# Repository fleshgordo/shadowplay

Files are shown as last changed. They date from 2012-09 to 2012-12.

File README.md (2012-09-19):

---------------------------------------------------------------

TIAN shadowplay - robotic light installation

Copyright Gordan Savicic 2012.

This program is free software: you can redistribute it
and/or modify it under the terms of the GNU Lesser General
Public License as published by the Free Software Foundation,
either version 3 of the License, or (at your option) any 
later version.

This program is distributed in the hope that it will be
useful, but WITHOUT ANY WARRANTY; without even the implied
warranty of MERCHANTABILITY or FITNESS FOR A PARTICULAR
PURPOSE.  See the GNU Lesser General Public License for more
details.

You should have received a copy of the GNU Lesser General
Public License along with this program.  If not, see
<http://www.gnu.org/licenses/>.

---------------------------------------------------------------

Shadowplay is a light installation for TIAN's chandelier
(www.tian-vienna.com) 
Concept & Production by design agency STRUKT Vienna 
(www.strukt.com) 
Light Design & Hardware by Gordan Savicic 
(www.yugo.at)

Two pan/tilt robotic units equipped with 10W LEDs were
installed inside the chandelier.  Through algorithmic
controlling of light positioning and brightness (PWM), they
produce different shadows along the ceiling and walls,
inviting the participator to experience various
patterns and reflections which subsequently form
their own spatial narrative.

---------------------------------------------------------------

Main hardware parts (see /schematics folder for CAD files):

* Arduino Mega (www.arduino.cc/en/Main/ArduinoBoardMega)
* Wifi Shield (www.arduino.cc/en/Main/ArduinoWiFiShield)
* 10W warm-white LEDs (www.reichelt.de) Constant Current
* Drivers BUCK (www.led-tech.de) 
* Glass Lenses (Lens Reflector 10W www.hero-ledstore.com)
* Custom PCB 
* Custom Aluminium pan/tilt unit (see /cnc folder for drawings)
  based on Lynx B Pan and Tilt kit (www.lynxmotion.com)

Software:

* written in C (see /firmware folder)

---------------------------------------------------------------

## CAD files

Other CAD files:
cnc/PANTILT_WITHOUTLENS.DXF
cnc/PANTILT_WITHLENS.DXF
cnc/PANTILT_MOUNTINGPLATE.DXF
cnc/PANTILT_MOUNTINGPLATE.DWG
cnc/PANTILT_WITHLENS.DWG
cnc/PANTILT_WITHOUTLENS.DWG

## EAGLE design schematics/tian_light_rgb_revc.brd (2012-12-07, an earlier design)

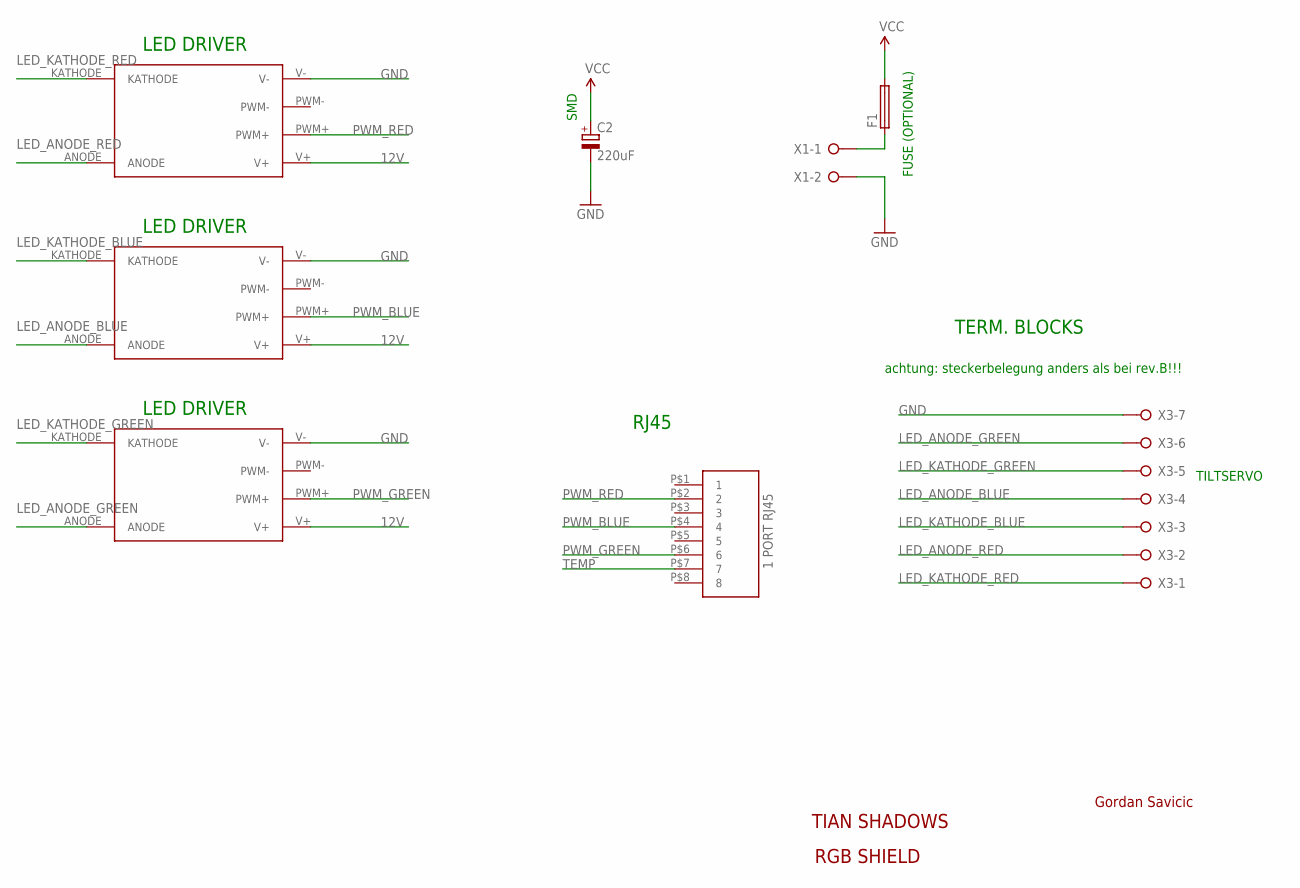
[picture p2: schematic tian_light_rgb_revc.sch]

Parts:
C2: 220uF; PANASONIC_F
F1: SH22,5
U$1, U$2, U$3: BUCK_LED_DRIVER
U$5: 1PORT_ETHERNET
X1: W237-02P; W237-132
X3: W237-07P; W237-7P

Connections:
12V: C2.+, F1.2, U$1.V+, U$2.V+, U$3.V+
GND: C2.-, U$1.V-, U$2.V-, U$3.V-, X1.2, X3.7
LED_ANODE_BLUE: U$2.ANODE, X3.4
LED_ANODE_GREEN: U$3.ANODE, X3.6
LED_ANODE_RED: U$1.ANODE, X3.2
LED_KATHODE_BLUE: U$2.KATHODE, X3.3
LED_KATHODE_GREEN: U$3.KATHODE, X3.5
LED_KATHODE_RED: U$1.KATHODE, X3.1
unnamed: F1.1, X1.1
PWM_BLUE: U$2.PWM+, U$5.P$4 (4)
PWM_GREEN: U$3.PWM+, U$5.P$6 (6)
PWM_RED: U$1.PWM+, U$5.P$2 (2)
TEMP: U$5.P$7 (7)

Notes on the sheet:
TILTSERVO
TIAN SHADOWS
RGB SHIELD
Gordan Savicic
RJ45
TERM. BLOCKS
LED DRIVER
achtung: steckerbelegung anders als bei rev.B!!!
FUSE (OPTIONAL)
SMD

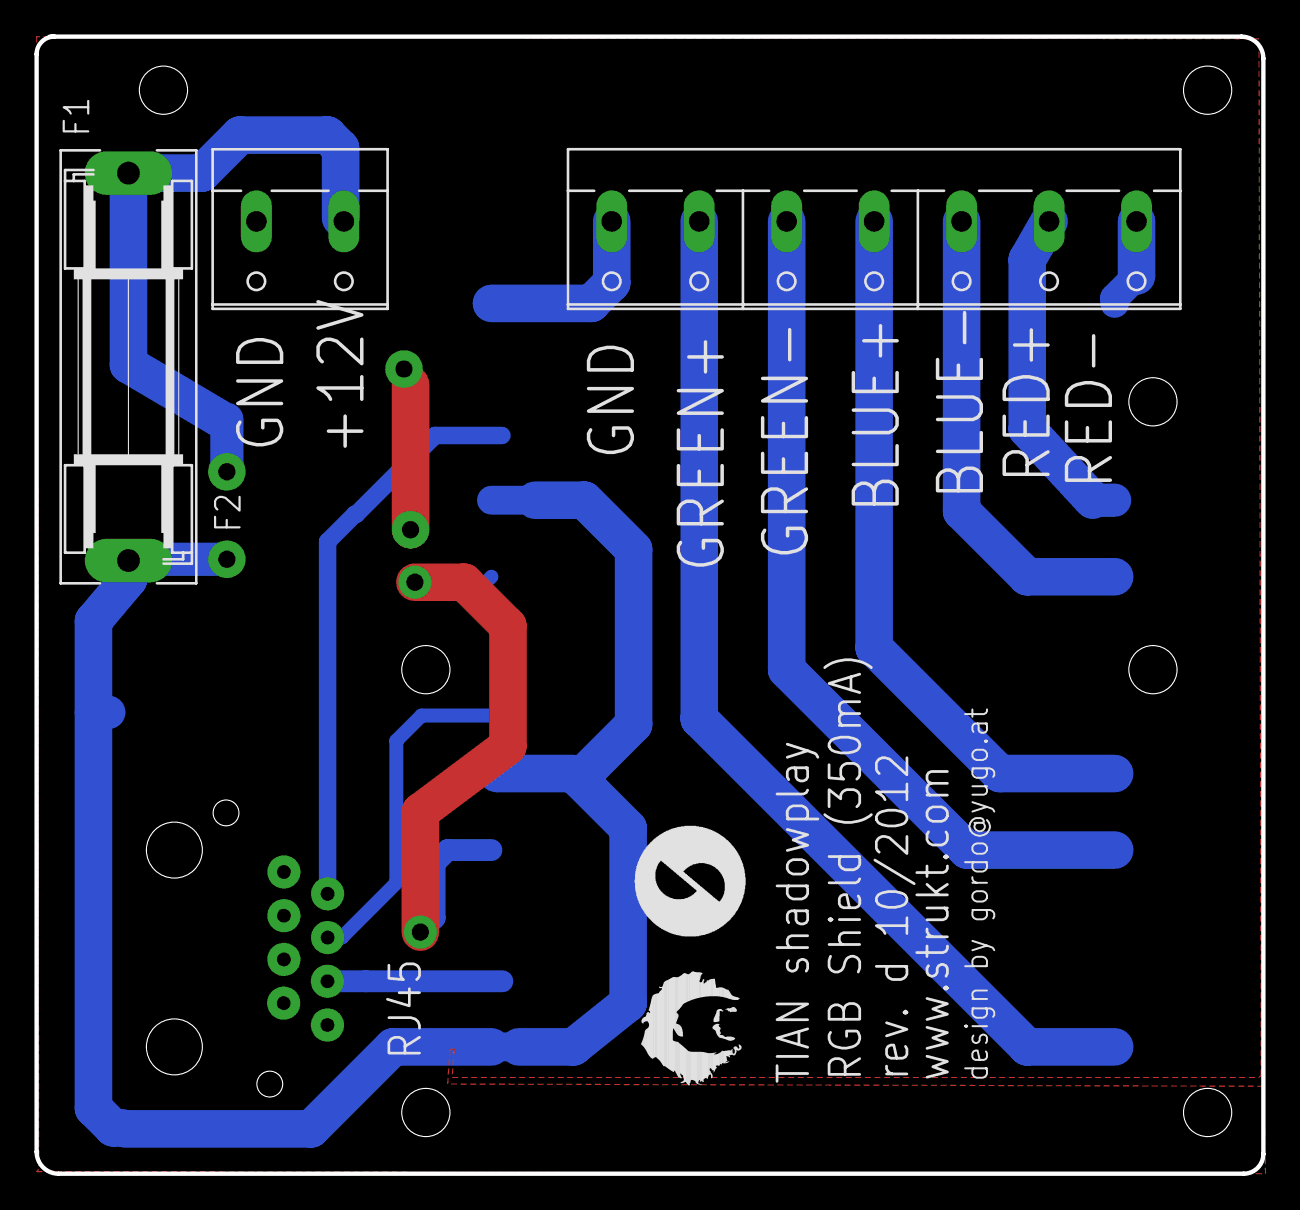
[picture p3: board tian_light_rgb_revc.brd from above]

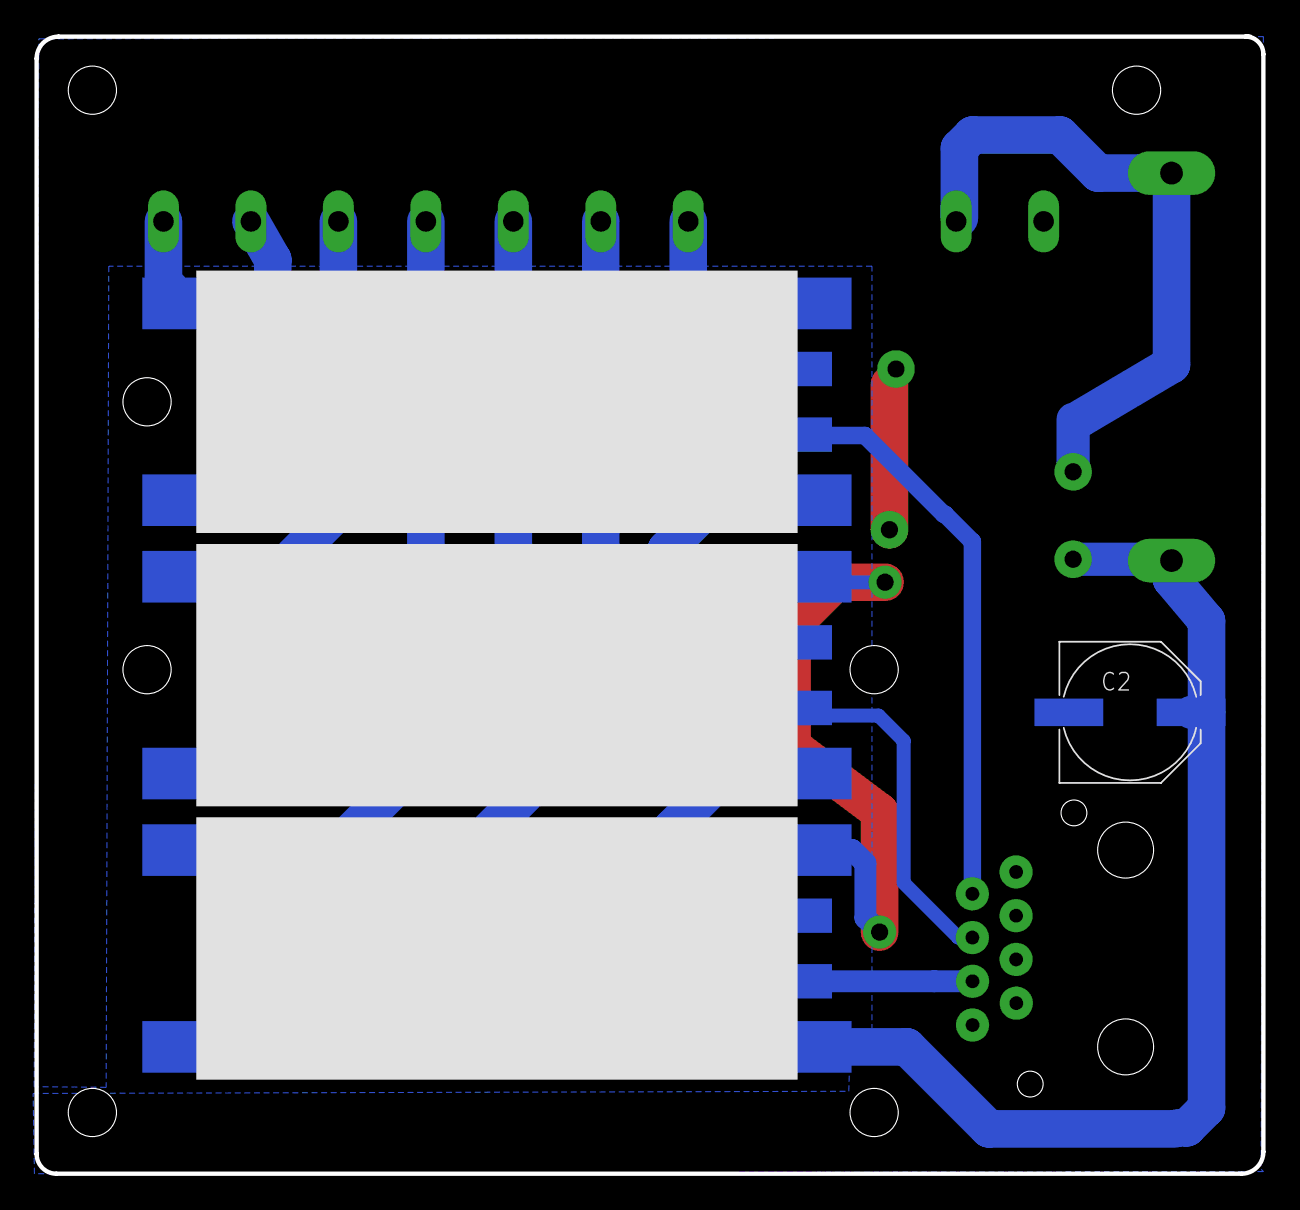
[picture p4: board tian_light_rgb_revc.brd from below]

Board: 2 copper layers, 71.2 x 66.0 mm, 8 parts (5 on the bottom side), 12 nets.

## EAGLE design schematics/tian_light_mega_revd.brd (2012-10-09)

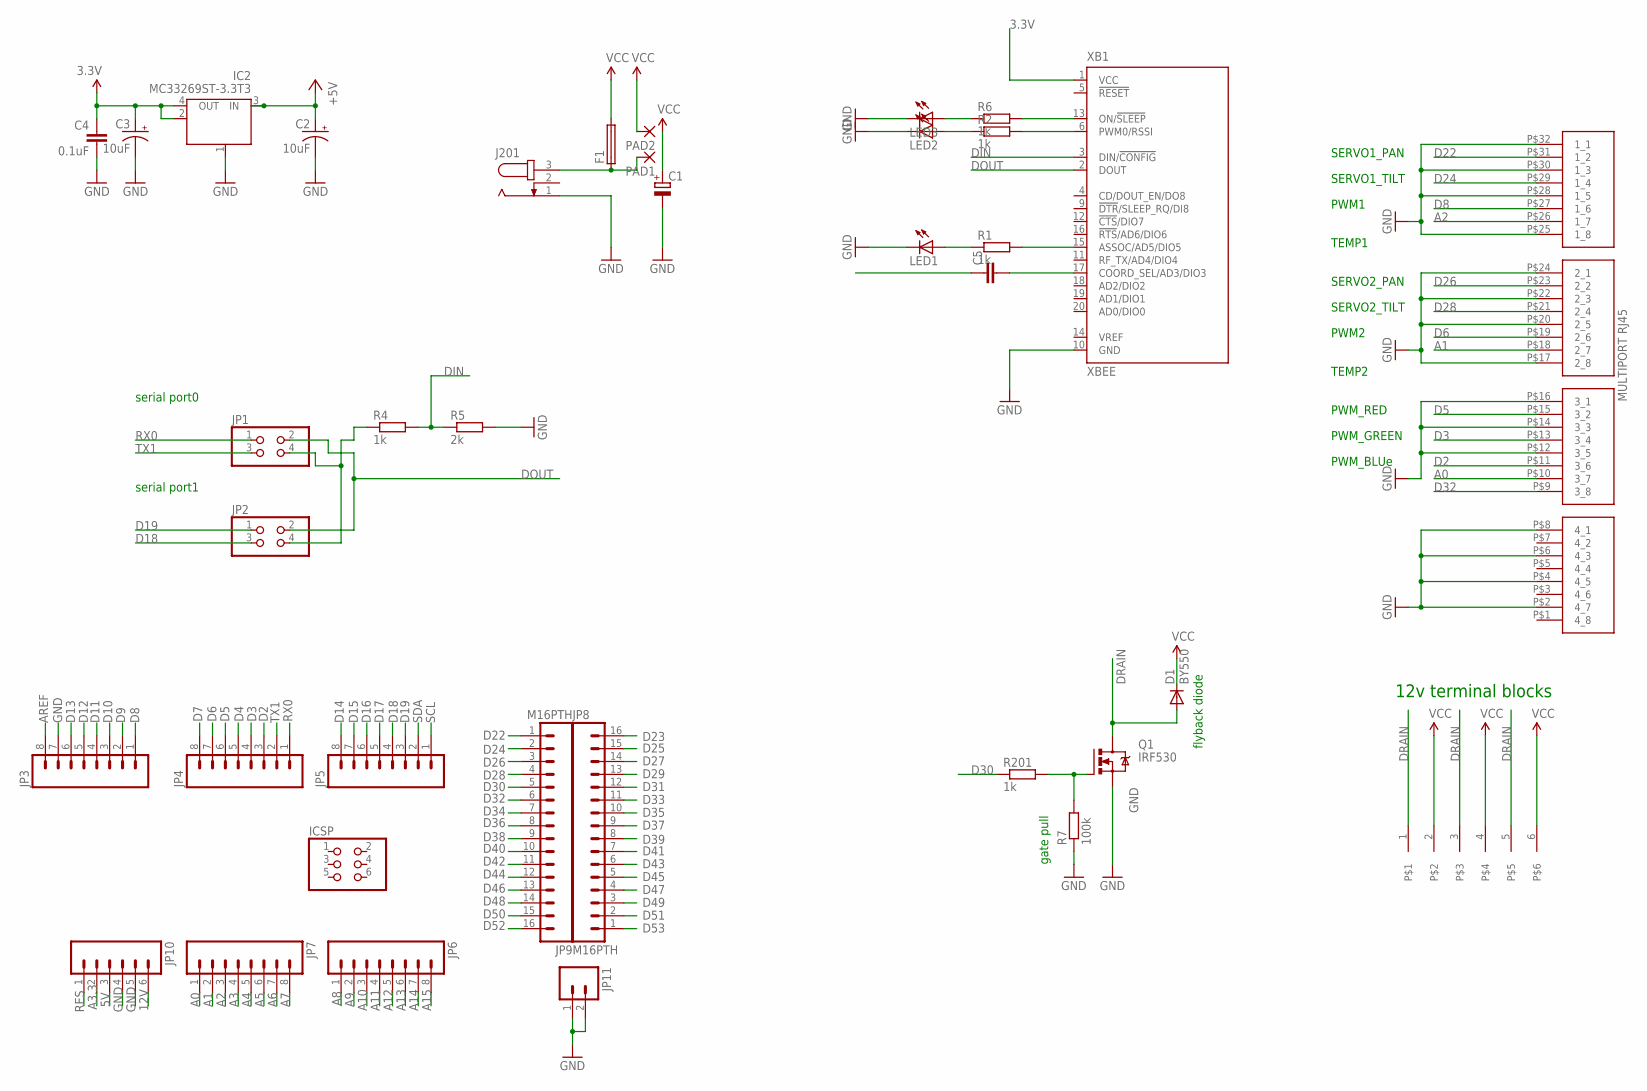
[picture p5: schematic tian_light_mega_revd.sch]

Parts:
C1: CPOL-EU153CLV-0605; 153CLV-0605
C2, C3: 10uF; EIA3216
C4: 0.1uF; 0603-CAP
C5: C-EUC0805; C0805
D1: BY550; DO27-15
F1: SH22,5
IC2: MC33269ST-3.3T3; SOT223
ICSP: PINHD-2X3; 2X03
J201: JACK-PLUG0; SPC4077
JP1, JP2: PINHD-2X2; 2X02
JP3, JP4, JP5, JP6, JP7: M08LONGPADS; 1X08_LONGPADS
JP8, JP9: M16PTH; 1X16
JP10: M06SIP; 1X06
JP11: M02LOCK; 1X02_LOCK
LED1, LED2, LED3: LEDSML1206; SML1206
PAD1, PAD2: 2,15/1,0
PORT201: 4PORT_ETHERNET
Q1: IRF530; TO220BV
R1, R2, R4, R6, R201: 1k; M1206
R5: 2k; M1206
R7: 100k; M1206
U$3: MFKDSP6-5.08; PHONEIX
XB1: XBEE

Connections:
3.3V: C3.A (+), C4.1, IC2.2 (OUT), IC2.4 (OUT), XB1.1 (VCC)
5V: C2.A (+), IC2.3 (IN), JP10.3
12V: C1.+, F1.2, JP10.6, PAD2.1, U$3.2, U$3.4, U$3.6
A0: JP7.1, PORT201.P$10 (3_7)
A1: JP7.2, PORT201.P$18 (2_7)
A2: JP7.3, PORT201.P$26 (1_7)
A3: JP7.4
A3.3: JP10.2
A4: JP7.5
A5: JP7.6
A6: JP7.7
A7: JP7.8
A8: JP6.1
A9: JP6.2
A10: JP6.3
A11: JP6.4
A12: JP6.5
A13: JP6.6
A14: JP6.7
A15: JP6.8
AREF: JP3.8
D2: JP4.3, PORT201.P$11 (3_6)
D3: JP4.4, PORT201.P$13 (3_4)
D4: JP4.5
D5: JP4.6, PORT201.P$15 (3_2)
D6: JP4.7, PORT201.P$19 (2_6)
D7: JP4.8
D8: JP3.1, PORT201.P$27 (1_6)
D9: JP3.2
D10: JP3.3
D11: JP3.4
D12: JP3.5
D13: JP3.6
D14: JP5.8
D15: JP5.7
D16: JP5.6
D17: JP5.5
D18: JP2.3, JP5.4
D19: JP2.1, JP5.3
D22: JP9.1, PORT201.P$31 (1_2)
D23: JP8.16
D24: JP9.2, PORT201.P$29 (1_4)
D25: JP8.15
D26: JP9.3, PORT201.P$23 (2_2)
D27: JP8.14
D28: JP9.4, PORT201.P$21 (2_4)
D29: JP8.13
D30: JP9.5, R201.1
D31: JP8.12
D32: JP9.6, PORT201.P$9 (3_8)
D33: JP8.11
D34: JP9.7
D35: JP8.10
D36: JP9.8
D37: JP8.9
D38: JP9.9
D39: JP8.8
D40: JP9.10
D41: JP8.7
D42: JP9.11
D43: JP8.6
D44: JP9.12
D45: JP8.5
D46: JP9.13
D47: JP8.4
D48: JP9.14
D49: JP8.3
D50: JP9.15
D51: JP8.2
D52: JP9.16
D53: JP8.1
DIN: R4.2, R5.1, XB1.3 (DIN/!CONFIG)
DOUT: JP1.2, JP2.2, XB1.2 (DOUT)
DRAIN: D1.A, Q1.D, U$3.1, U$3.3, U$3.5
GND: C1.-, C2.C (-), C3.C (-), C4.2, IC2.1 (GND/ADJ), J201.1, JP3.7, JP10.4, JP10.5, JP11.1, JP11.2, LED1.C, LED2.C, LED3.C, PORT201.P$2 (4_7), PORT201.P$4 (4_5), PORT201.P$6 (4_3), PORT201.P$8 (4_1), PORT201.P$12 (3_5), PORT201.P$14 (3_3), PORT201.P$16 (3_1), PORT201.P$17 (2_8), PORT201.P$20 (2_5), PORT201.P$22 (2_3), PORT201.P$24 (2_1), PORT201.P$25 (1_8), PORT201.P$28 (1_5), PORT201.P$30 (1_3), PORT201.P$32 (1_1), Q1.S, R5.2, R7.1, XB1.10 (GND)
unnamed: JP1.4, JP2.4, R4.1
unnamed: LED1.A, R1.1
unnamed: Q1.G, R7.2, R201.2
unnamed: R1.2, XB1.15 (ASSOC/AD5/DIO5)
unnamed: R6.2, XB1.13 (ON/!SLEEP)
unnamed: LED2.A, R2.1
unnamed: R2.2, XB1.6 (PWM0/RSSI)
unnamed: LED3.A, R6.1
unnamed: C5.2, XB1.17 (COORD_SEL/AD3/DIO3)
unnamed: F1.1, J201.3, PAD1.1
RES: C5.1, JP10.1
RX0: JP1.1, JP4.1
SCL: JP5.1
SDA: JP5.2
TX1: JP1.3, JP4.2
VCC: D1.C

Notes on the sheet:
12v terminal blocks
SERVO1_PAN
SERVO1_TILT
PWM1
TEMP1
SERVO2_PAN
SERVO2_TILT
PWM2
TEMP2
PWM_RED
PWM_GREEN
PWM_BLUe
flyback diode
gate pull
serial port1
serial port0

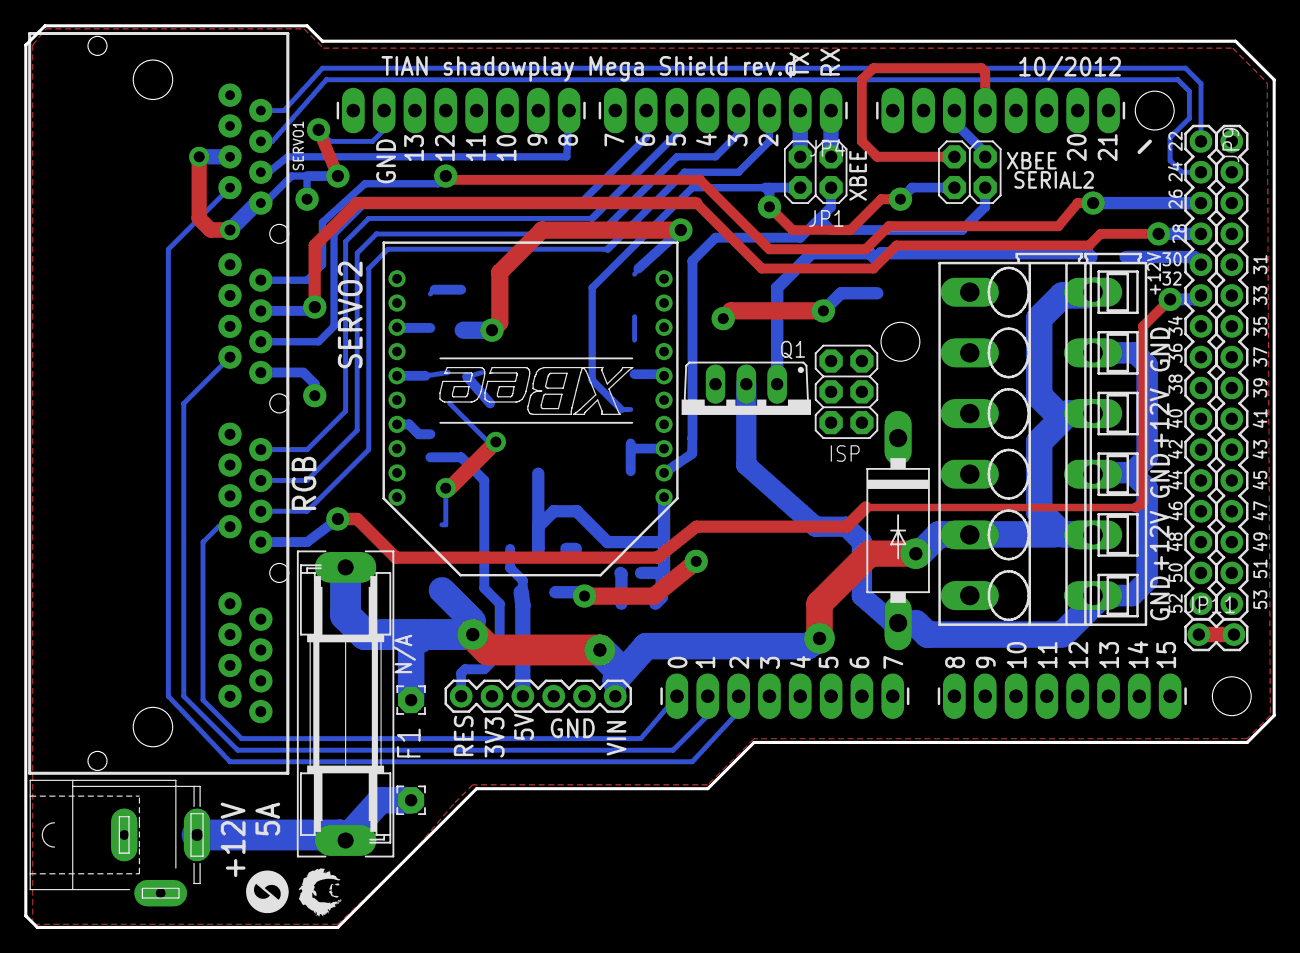
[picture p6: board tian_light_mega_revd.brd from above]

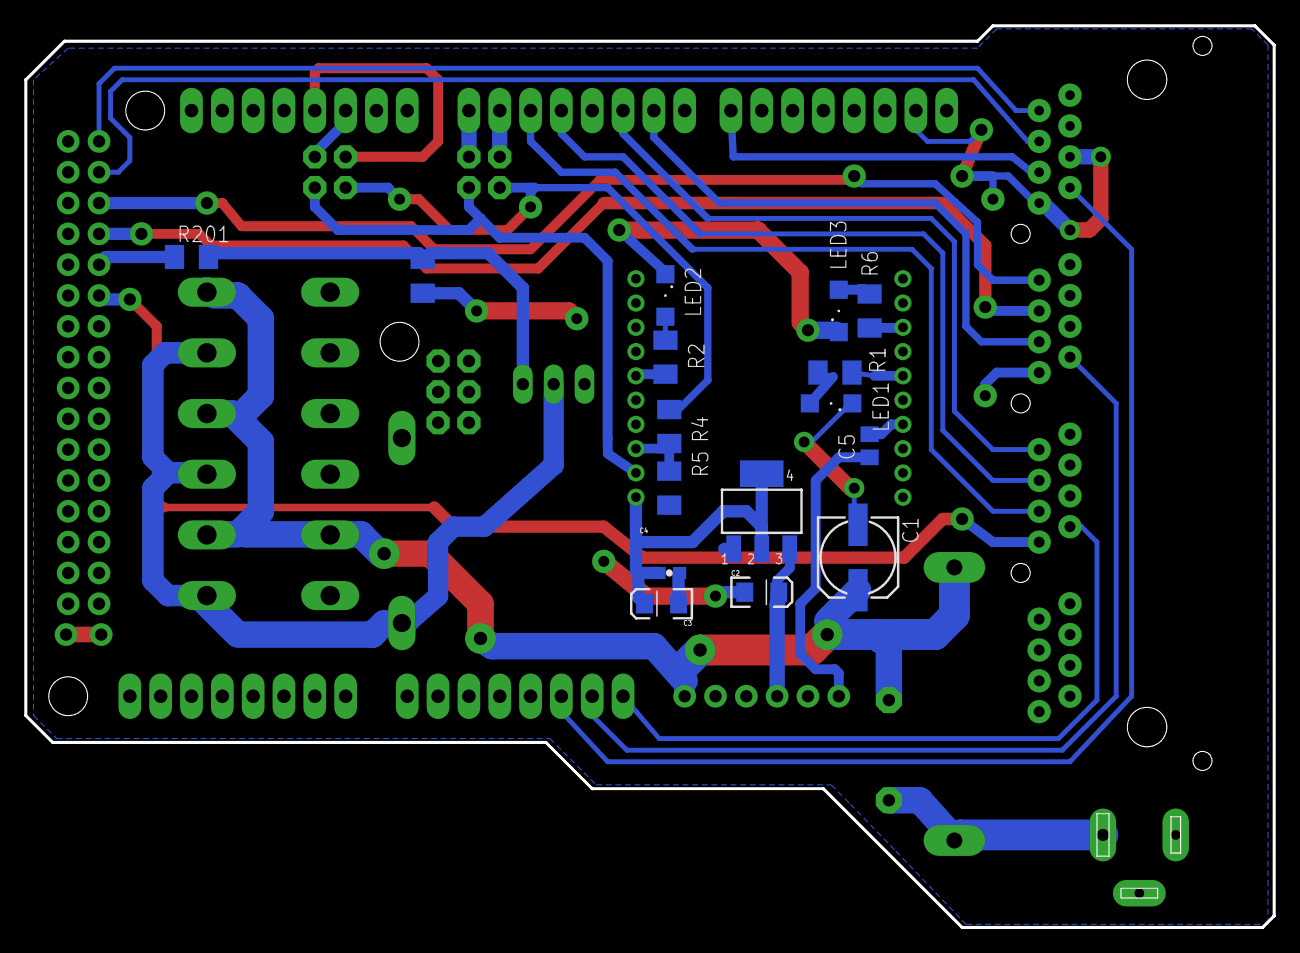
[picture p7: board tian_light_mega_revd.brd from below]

Board: 2 copper layers, 102.9 x 74.3 mm, 37 parts (16 on the bottom side), 36 nets.

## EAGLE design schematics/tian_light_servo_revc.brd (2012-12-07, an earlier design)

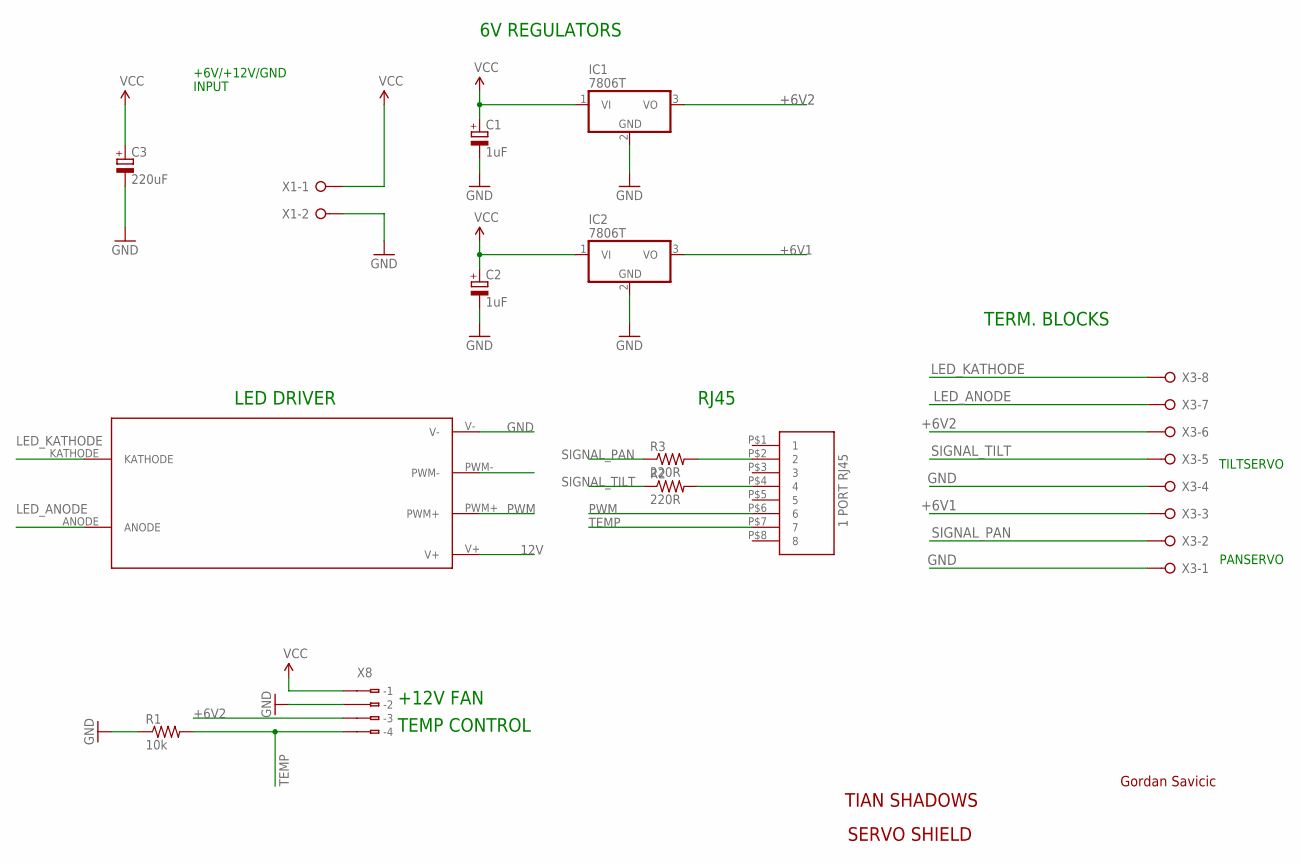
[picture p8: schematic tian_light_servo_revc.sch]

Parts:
C1, C2: 1uF; SMC_C
C3: 220uF; 153CLV-0605
IC1, IC2: 7806T; TO220H
R1: 10k; 1206
R2, R3: 220R; 1206
U$1: BUCK_LED_DRIVER
U$5: 1PORT_ETHERNET
X1: W237-02P; W237-132
X3: W237-08P; W237-8P
X8: 233-104

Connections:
12V: C1.+, C2.+, C3.+, IC1.1 (VI), IC2.1 (VI), U$1.V+, X1.1, X8.B1 (B-1)
+6V1: IC2.3 (VO), X3.3
+6V2: IC1.3 (VO), X3.6, X8.B3 (B-3)
GND: C1.-, C2.-, C3.-, IC1.2 (GND), IC2.2 (GND), R1.1, U$1.V-, X1.2, X3.1, X3.4, X8.B2 (B-2)
LED_ANODE: U$1.ANODE, X3.7
LED_KATHODE: U$1.KATHODE, X3.8
unnamed: R2.2, U$5.P$4 (4)
unnamed: R3.2, U$5.P$2 (2)
PWM: U$1.PWM+, U$5.P$6 (6)
SIGNAL_PAN: R3.1, X3.2
SIGNAL_TILT: R2.1, X3.5
TEMP: R1.2, U$5.P$7 (7), X8.B4 (B-4)

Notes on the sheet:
+6V/+12V/GND
INPUT
+12V FAN
TEMP CONTROL
PANSERVO
TILTSERVO
TIAN SHADOWS
SERVO SHIELD
Gordan Savicic
6V REGULATORS
RJ45
TERM. BLOCKS
LED DRIVER

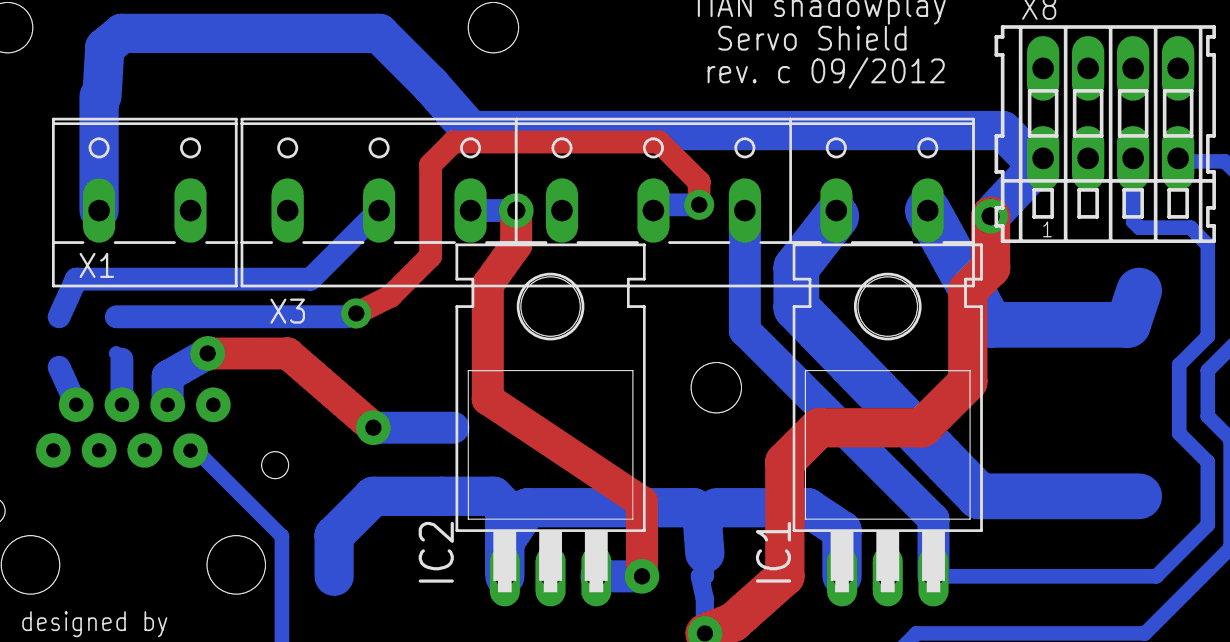
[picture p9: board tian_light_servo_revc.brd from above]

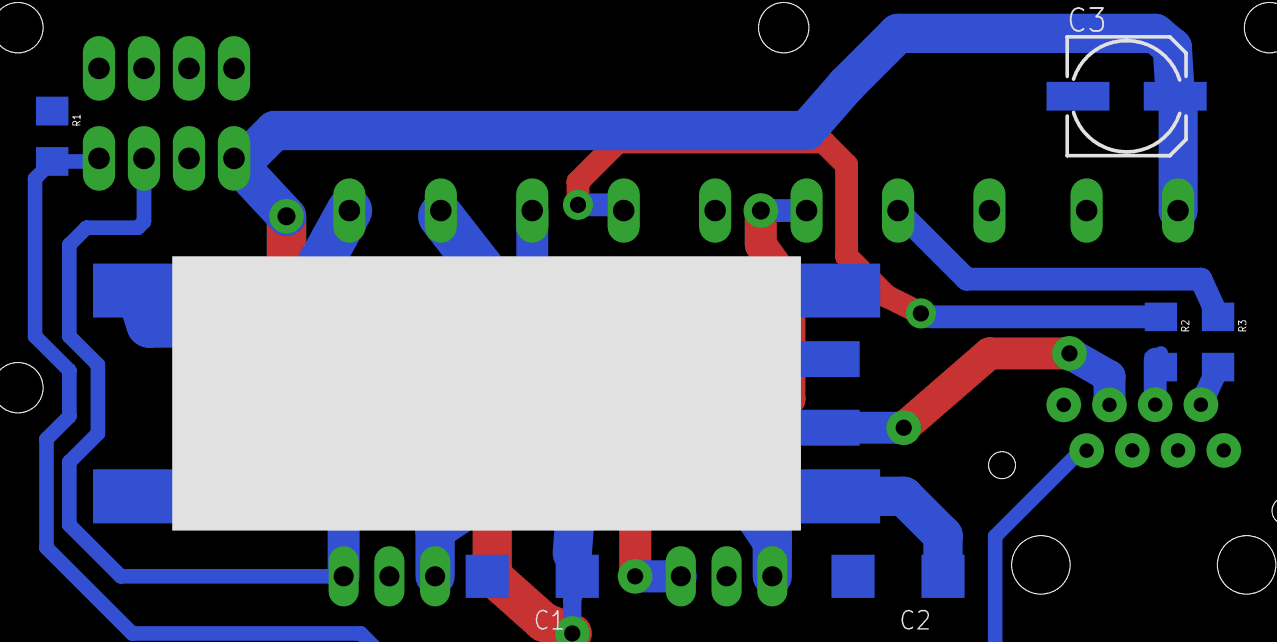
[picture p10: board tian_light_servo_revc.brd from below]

Board: 2 copper layers, 13 parts (8 on the bottom side), 12 nets.

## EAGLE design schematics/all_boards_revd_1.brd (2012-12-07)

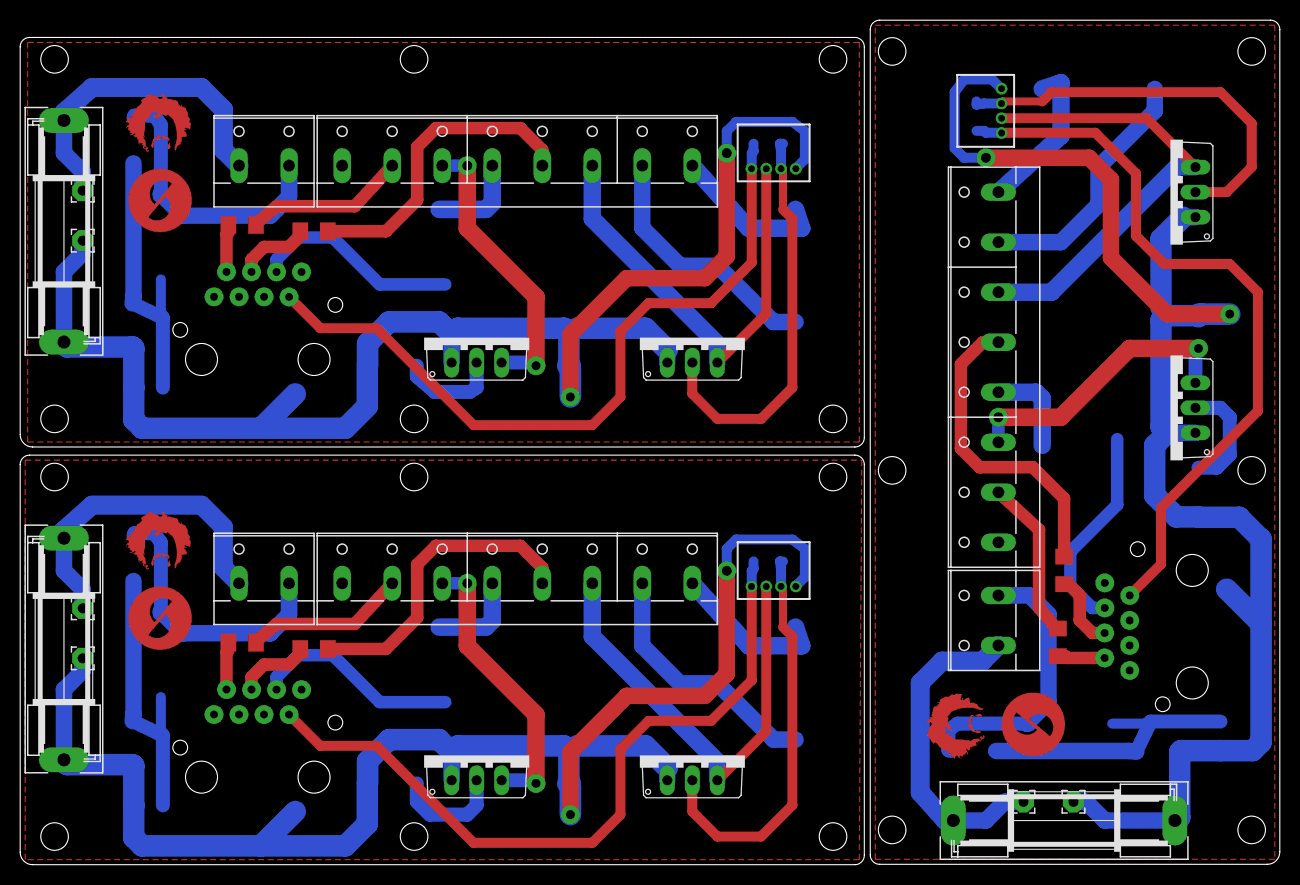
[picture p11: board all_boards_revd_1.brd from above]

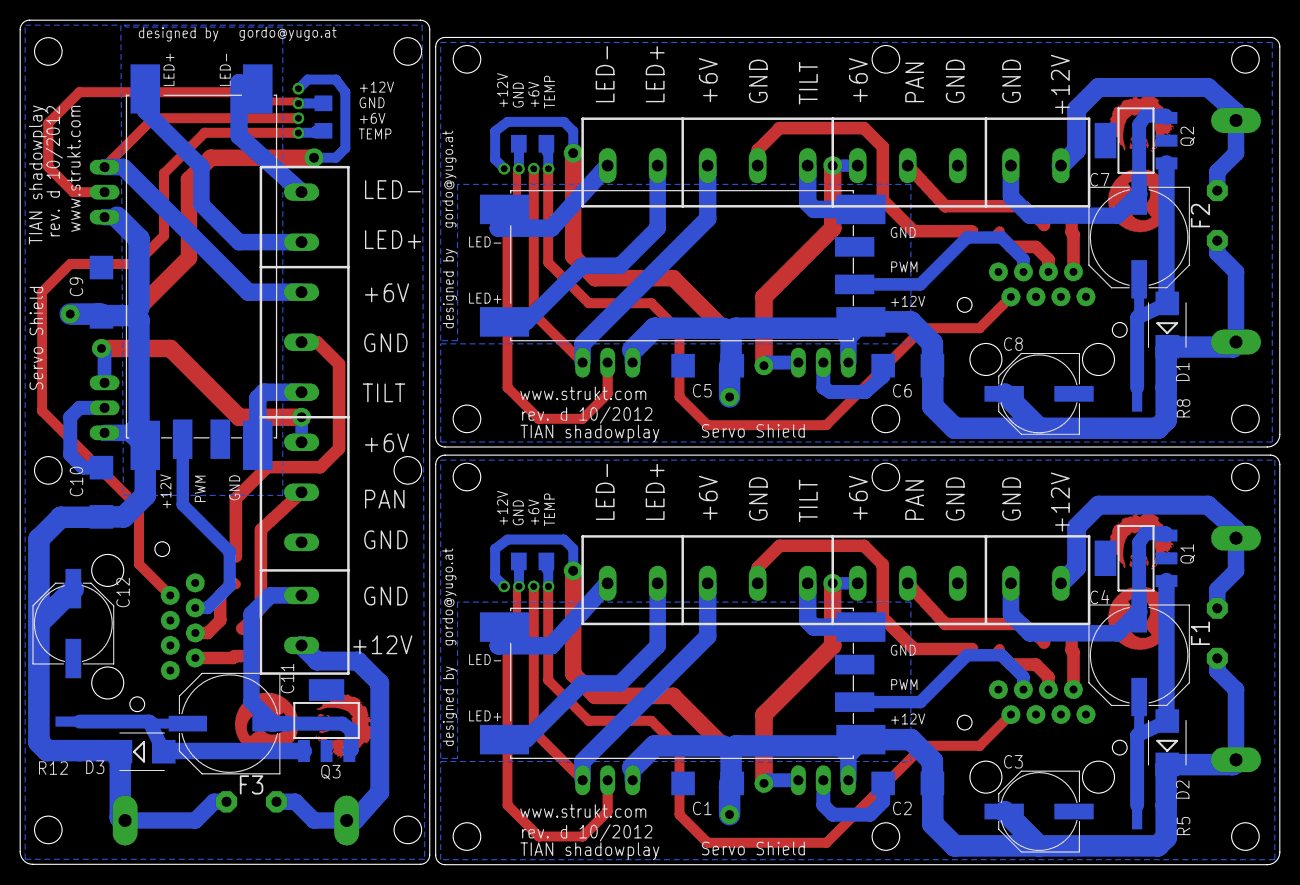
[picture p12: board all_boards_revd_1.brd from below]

Board: 2 copper layers, 127.9 x 85.8 mm, 60 parts (30 on the bottom side), 45 nets.

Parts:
C1, C2, C5, C6, C9, C10: 1uF; SMC_C
C3, C8, C12: 220uF; PANASONIC_F
C4, C7, C11: 10-20uF; PANASONIC_G
D1, D2, D3: ES2D; SMB
F1, F2, F3: SH22,5
IC1, IC2, IC3, IC4, IC5, IC6: 7805TV; TO220V
PAD1, PAD2, PAD3, PAD4, PAD5, PAD6: 2,15/1,0
Q1, Q2, Q3: N-HEXFET-2D_SOT232-; SOT223
R1, R4, R9: 10k; 1206
R2, R3, R6, R7, R10, R11: 220R; 1206
R5, R8, R12: 470k; R1218
U$1, U$2, U$4: BUCK_LED_DRIVER
U$3, U$5, U$6: 1PORT_ETHERNET
X1, X5, X8: W237-132
X2, X3, X7: W237-8P
X4, X6, X9: S4B-ZR

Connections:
12V: C1.+, C2.+, C3.+, D2.C, F1.2, IC3.1, IC4.1, PAD1.1, R5.2, U$1.V+, X4.1
12V1: C5.+, C6.+, C8.+, D1.C, F2.2, IC1.1, IC2.1, PAD3.1, R8.2, U$2.V+, X6.1
12V2: C9.+, C10.+, C12.+, D3.C, F3.2, IC5.1, IC6.1, PAD5.1, R12.2, U$4.V+, X9.1
+6V1: IC4.3, X3.3
+6V2: IC3.3, X3.6, X4.3
+6V3: IC1.3, X2.6, X6.3
+6V4: IC2.3, X2.3
+6V5: IC5.3, X7.6, X9.3
+6V6: IC6.3, X7.3
GND: C1.-, C2.-, C3.-, IC3.2, IC4.2, Q1.2, Q1.4, R1.1, U$1.V-, X3.1, X3.4, X4.2
GND1: C5.-, C6.-, C8.-, IC1.2, IC2.2, Q2.2, Q2.4, R4.1, U$2.V-, X2.1, X2.4, X6.2
GND2: C9.-, C10.-, C12.-, IC5.2, IC6.2, Q3.2, Q3.4, R9.1, U$4.V-, X7.1, X7.4, X9.2
GND_INPUT: C4.-, Q1.3, X1.2
GND_INPUT1: C7.-, Q2.3, X5.2
GND_INPUT2: C11.-, Q3.3, X8.2
LED_ANODE: U$1.ANODE, X3.7
LED_ANODE1: U$2.ANODE, X2.7
LED_ANODE2: U$4.ANODE, X7.7
LED_KATHODE: U$1.KATHODE, X3.8
LED_KATHODE1: U$2.KATHODE, X2.8
LED_KATHODE2: U$4.KATHODE, X7.8
unnamed: R2.2, U$5.P$4
unnamed: R3.2, U$5.P$2
unnamed: C4.+, D2.A, Q1.1, R5.1
unnamed: F1.1, PAD2.1, X1.1
unnamed: R6.2, U$3.P$4
unnamed: R7.2, U$3.P$2
unnamed: C7.+, D1.A, Q2.1, R8.1
unnamed: F2.1, PAD4.1, X5.1
unnamed: R10.2, U$6.P$4
unnamed: R11.2, U$6.P$2
unnamed: C11.+, D3.A, Q3.1, R12.1
unnamed: F3.1, PAD6.1, X8.1
PWM: U$1.PWM+, U$5.P$6
PWM1: U$2.PWM+, U$3.P$6
PWM2: U$4.PWM+, U$6.P$6
SIGNAL_PAN: R3.1, X3.2
SIGNAL_PAN1: R7.1, X2.2
SIGNAL_PAN2: R11.1, X7.2
SIGNAL_TILT: R2.1, X3.5
SIGNAL_TILT1: R6.1, X2.5
SIGNAL_TILT2: R10.1, X7.5
TEMP: R1.2, U$5.P$7, X4.4
TEMP1: R4.2, U$3.P$7, X6.4
TEMP2: R9.2, U$6.P$7, X9.4

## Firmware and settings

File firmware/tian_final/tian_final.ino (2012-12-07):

#include <Servo.h> 
#include <SPI.h>
#include <WiFi.h>
#include <math.h>

Servo Servo1_pan;  // create servo object to control a servo 
Servo Servo1_tilt;

Servo Servo2_pan;  // create servo object to control a servo 
Servo Servo2_tilt;

String currentLine = ""; 
String tweet = ""; 

// PINS
const int mosfet12 =  30;     
const int Light1PWM = 8;
const int Light2PWM = 6;
const int RedPWM = 5;
const int GreenPWM = 2;
const int BluePWM = 3;


// MAXIMUM ratings
const int ServoPanLeftmax = 25;
const int ServoPanRightmax = 160;
const int ServoTiltUpmax = 165;
const int ServoTiltDownmax = 98;

const int ServoTiltCenter = (ServoTiltUpmax + ServoTiltDownmax) /2;
const int ServoPanCenter = (ServoPanLeftmax + ServoPanRightmax) /2;

float radius = 68;

float step1 = 0;
float stepc1 = 0;
float step2 = PI;
float stepc2 = 0;
float rgbStep = 0.0;
float rgbSpeed = 0.0;
float rStep=0.0;
float gStep=0.0;
float bStep=0.0;

float sinus1=0;
float sinus2=PI/4;

float speed1=0.00123f;
float speedc1=0.00304f;
float speed2=0.00123f;
float speedc2=0.000304f;

int oldX1=0;
int oldX2=0;
int oldY1=0;
int oldY2=0;
boolean firstPosition=true;
int sequence=-2;
int sTimer=0;
float lin1=0;
float lin2=0;
float dlin1=0.01;
float dlin2=0.01;

int rrr=0;
int ggg=0;
int bbb=0;

int MAXMAX_BRIGHT = 255;
int MINMAX_BRIGHT = 0;
int MAX_BRIGHT = MAXMAX_BRIGHT;

boolean hasChecked=false;
int darkTimer=0;
int darkTimer2=0;
int lastBright1=0;
int lastBright2=0;

int maxservo = 165;
int minservo = 15;
int red, green, blue;

int Servo1Temp = 2;
int Servo2Temp = 1;
int Servo3Temp = 0;

int pausi=0;

int LightBrightness = 0;

int server_timeout = 0;

float step = 0;
float steps[] = {0, 0.13962634, 0.27925268, 0.41887902, 0.55850536, 0.6981317, 0.83775804,
0.97738438, 1.11701072, 1.25663706, 1.3962634, 1.53588974, 1.67551608, 1.81514242,
1.95476876, 2.0943951, 2.23402144, 2.37364778, 2.51327412, 2.65290046, 2.7925268,
2.93215314, 3.07177948, 3.21140582, 3.35103216, 3.4906585, 3.63028484, 3.76991118,
3.90953752, 4.04916386, 4.1887902, 4.32841654, 4.46804289, 4.60766923, 4.74729557,
4.88692191, 5.02654825, 5.16617459, 5.30580093, 5.44542727, 5.58505361, 5.72467995,
5.86430629, 6.00393263, 6.14355897};

const int steplength = sizeof(steps)/2;


// RGB
float RGB1[3];
float RGB2[3];
float INC[3];

// WIFI STUFF
char ssid[] = "ff20d"; 
char pass[] = "#?1)CNq(Vqvw&y3(lg9";   
char nameserver[] = "10.10.0.31";
int keyIndex = 0;         

boolean wifi_shield = true;
boolean wifi_enable = true;
boolean isConnected=false;

int status = WL_IDLE_STATUS;
IPAddress server(10,10,0,31);
WiFiClient client;

void setup() {
  currentLine.reserve(256);
  tweet.reserve(100);
  Serial.begin(19200);
  // set the digital pin as output:
  pinMode(mosfet12, OUTPUT);
  pinMode(Light1PWM, OUTPUT);
  pinMode(Light2PWM, OUTPUT);
  pinMode(BluePWM, OUTPUT);
  pinMode(RedPWM, OUTPUT);
  pinMode(GreenPWM, OUTPUT);
  set_brightness(5);
  
  digitalWrite(mosfet12, HIGH);
  
  Servo1_pan.attach(22);
  Servo1_tilt.attach(24);
  Servo2_pan.attach(26);
  Servo2_tilt.attach(28);
  
  Servo1_pan.write(90);
  Servo1_tilt.write(110);  
  Servo2_pan.write(90);
  Servo2_tilt.write(110);

  // some rgb randomseeds
  randomSeed(analogRead(6));
  for (int x=0; x<3; x++) {
  RGB1[x] = random(256);
  RGB2[x] = random(256); }

  if (wifi_enable == true) {
   // check for the presence of the shield:
    if (WiFi.status() == WL_NO_SHIELD) {
      Serial.println("WiFi shield not present"); 
      wifi_shield = false;
    }    
    if (wifi_shield == true) {
      // attempt to connect to Wifi network:
      while ( status != WL_CONNECTED) { 
        Serial.print("Attempting to connect to SSID: ");
        Serial.println(ssid);
        // Connect to WPA/WPA2 network. Change this line if using open or WEP network:    
        status = WiFi.begin(ssid, pass);
        // wait 10 seconds for connection:
        delay(8000);
      } 
      Serial.println("Connected to wifi");
      printWifiStatus();
      
      Serial.println("\nStarting connection to server...");
      // if you get a connection, report back via serial:
      if (client.connect(nameserver, 80)){
        isConnected=true;
        sequence=-1;
        Serial.println("connected to server");
        // Make a HTTP request:
        client.println("GET / HTTP/1.1");
        client.println("Host:localhost");
        client.println("Connection: close");
        client.println();
      }
    }
  }
}

void make_request() {
  Serial.println("\nStarting connection to server...");
  if (client.connect(server, 80)) {
    Serial.println("connected to server");
    client.println("GET / HTTP/1.1");
    client.println("Host:localhost");
    client.println("Connection: close");
    client.println();
    server_timeout=0;
    isConnected=true;
  }else{
    isConnected=false;
    server_timeout++;
    if (server_timeout>5){
      sequence=0;
      server_timeout=0;
    }
    Serial.println("server timeout");  }
}

int getIntFromString(String s){
  char ca[s.length()+1];
  s.toCharArray(ca,(s.length()+1));
  return atoi(ca);
}

void server_check() {
  make_request();
  while (client.available()) {
  char inChar = client.read();
  // add incoming byte to end of line:
      //Serial.write(inChar);
      currentLine += inChar;

      // if you get a newline, clear the line:
      if (inChar == '\n') {
        currentLine = "";
      } 
      if ( currentLine.endsWith("</html>")) {
        String content = currentLine.substring(currentLine.indexOf("<body>")+6,currentLine.indexOf("</body>"));
        int kommaIndex1 = content.indexOf(",");
        int kommaIndex2 = content.indexOf(",",kommaIndex1+1);
        int kommaIndex3 = content.indexOf(",",kommaIndex2+1);
        int kommaIndex4 = content.indexOf(",",kommaIndex3+1);
        if(kommaIndex1!=-1){
          String s = content.substring(0,kommaIndex1);
          String br = content.substring(kommaIndex1+1,kommaIndex2);
          String rr = content.substring(kommaIndex2+1,kommaIndex3);
          String gg = content.substring(kommaIndex3+1,kommaIndex4);
          String bb = content.substring(kommaIndex4+1);
          sequence=getIntFromString(s);
          MAX_BRIGHT=getIntFromString(br);
          rrr=getIntFromString(rr);
          ggg=getIntFromString(gg);
          bbb=getIntFromString(bb);
          Serial.println();
          Serial.print("sequence: ");
          Serial.println(sequence);
          Serial.print("brightness: ");
          Serial.println(MAX_BRIGHT);
          Serial.print("red: ");
          Serial.println(rr);
          Serial.print("green: ");
          Serial.println(gg);
          Serial.print("blu: ");
          Serial.println(bb);
        }
      }
      
  }

}
void printWifiStatus() {
  Serial.print("SSID: ");
  Serial.println(WiFi.SSID());

  // print your WiFi shield's IP address:
  IPAddress ip = WiFi.localIP();
  Serial.print("IP Address: ");
  Serial.println(ip);

  long rssi = WiFi.RSSI();
  Serial.print("signal strength (RSSI):");
  Serial.print(rssi);
  Serial.println(" dBm");
}

void set_brightness(int brightness) {
    int new_brightness = map(brightness, 0, 100, 255, 0);
    analogWrite(BluePWM,new_brightness);
    analogWrite(RedPWM,new_brightness);
    analogWrite(GreenPWM,new_brightness);
    analogWrite(Light1PWM,new_brightness);
    analogWrite(Light2PWM,new_brightness);
  return;
}

void rgbled(int r1,int g1, int b1){
    b1=b1/2;
    r1=(r1*2)/3;
    int r2 = map(r1, 0, 255, MAXMAX_BRIGHT, MAXMAX_BRIGHT-MAX_BRIGHT);
    int g2 = map(g1, 0, 255, MAXMAX_BRIGHT, MAXMAX_BRIGHT-MAX_BRIGHT);
    int b2 = map(b1, 0, 255, MAXMAX_BRIGHT, MAXMAX_BRIGHT-MAX_BRIGHT);
        
    analogWrite(GreenPWM,g2);
    analogWrite(BluePWM,b2);
    analogWrite(RedPWM,r2);
}


void bright1(int brightness){
  if(brightness<15)brightness=15;
  lastBright1=brightness;
  int new_brightness = map(brightness, 0, 255, MAXMAX_BRIGHT, MAXMAX_BRIGHT-MAX_BRIGHT);
  analogWrite(Light1PWM,new_brightness);
}
void bright2(int brightness){
  if(brightness<15)brightness=15;
  lastBright2=brightness;
  int new_brightness = map(brightness, 0, 255, MAXMAX_BRIGHT, MAXMAX_BRIGHT-MAX_BRIGHT);
  analogWrite(Light2PWM,new_brightness);
}

void writePan(Servo servo, int svalue){
  if(svalue < ServoPanLeftmax)svalue=ServoPanLeftmax;
  if(svalue > ServoPanRightmax)svalue=ServoPanRightmax;
  servo.write(svalue);
}
void writeTilt(Servo servo, int svalue){
  if(svalue < ServoTiltDownmax)svalue=ServoTiltDownmax;
  if(svalue > ServoTiltUpmax)svalue=ServoTiltUpmax;
  servo.write(svalue);
}

void draw_circle(Servo servo_pan, Servo servo_tilt, int r, int i) 
{
  int x = float(ServoPanCenter) + float(r) * cos(i);
  int y = float(ServoTiltCenter) - float(r) * sin(i);
  writePan(servo_pan,x);
  writeTilt(servo_tilt,y);
     
//   if (x > ServoPanLeftmax && x < ServoPanRightmax && y < ServoTiltUpmax && y > ServoTiltDownmax) {
//    servo_pan.write(x);
//    servo_tilt.write(y);
//    Serial.print("x: ");
//   Serial.print(x);
//    Serial.print("y: ");
//   Serial.print(y);
//   Serial.println();
//   delay(delaytime);
//   }
// }
 return;
}

// move the servo a given amount
void moveServo(Servo servo, int delta) {
 int previousValue = servo.read();
 int newValue = previousValue + delta;
 if (newValue > maxservo || newValue < minservo) {
  return;
 }
 servo.write(newValue);
 Serial.println(newValue);
}

void color (unsigned int red, unsigned int green, unsigned int blue) { 	 
  analogWrite(RedPWM, 255-red); 	 
  analogWrite(BluePWM, 255-blue);
  analogWrite(GreenPWM, 255-green);
  
  return;
}


void rgbBlink(float blink1,float blink2){
    rgbStep+=blink1;
    rgbSpeed+=blink2;
    int rr=float(rrr)* (sin(rgbSpeed)+1)/2;
    int gg=float(ggg)* (sin(rgbSpeed)+1)/2;
    int bb=float(bbb)* (sin(rgbSpeed)+1)/2;
    rgbled(rr,gg,bb);
}
void rgbColorBlink(float blink1,float blink2){
    rgbStep+=blink1;
    rgbSpeed+=blink2;
    int rr = 127+127.0f*sin(rgbStep);
    int gg = 127+127.0f*cos(rgbStep);
    int bb = 127+127.0f*sin(rgbStep+(PI/2));
    rr=float(rr)* (sin(rgbSpeed)+1)/2;
    gg=float(gg)* (sin(rgbSpeed)+1)/2;
    bb=float(bb)* (sin(rgbSpeed)+1)/2;
    rgbled(rr,gg,bb);
}

void gBlink(float blink1){
  gStep+=blink1;
  int gg = 127+127.0f*cos(gStep);
  rgbled(0,gg,0);
}
void rBlink(float blink1){
  gStep+=blink1;
  int rr = 127+127.0f*cos(gStep);
  rgbled(rr,0,0);
}


void movement0(){
    step1+=speed1;
    step2+=speed2;
    stepc1+=speedc1;
    stepc2+=speedc2;
    int x1 = float(ServoPanCenter) + (radius*0.8) * cos(step1);
    int y1 = float(ServoTiltCenter-20) - (radius*0.14)  * sin(stepc1);
    int x2 = float(ServoPanCenter) + (radius*0.76) * cos(-step2);
    int y2 = float(ServoTiltCenter-20) - (radius*0.16) * sin(-stepc2);
    writePan(Servo1_pan,x1);
    writePan(Servo2_pan,x2);
    writeTilt(Servo1_tilt,y1);
    writeTilt(Servo2_tilt,y2);
}

void movement1(){
    step1+=speed1/2.25;
    step2+=speed2/2.25;
    
    float cosStep1=cos(step1);
    float cosStep2=cos(step2);
    float sinStep1=sin(step1);
    float sinStep2=sin(step2);
    float cosQ1=cosStep1*cosStep1;
    float cosQ2=cosStep2*cosStep2;
    
    int x1 = float(ServoPanCenter) + radius * cosStep1;
    int y1 = float(ServoTiltCenter-15) - (radius*0.02)  * sinStep1;
    int x2 = float(ServoPanCenter) + radius * cosStep2;
    int y2 = float(ServoTiltCenter-25) - (radius*0.02) * sinStep2;
  
    writePan(Servo1_pan,x1);
    writeTilt(Servo1_tilt,y1);
    writePan(Servo2_pan,x2);
    writeTilt(Servo2_tilt,y2);
    
    //movement1 is coupled with light
    lastBright1 = 255 - 255.0 * cosQ1;
    if(sinStep1>=0)lastBright1=0;
    bright1(lastBright1);
    lastBright2 = 255 - 255.0 * cosQ2;
    if(sinStep2>=0)lastBright2=0;
    bright2(lastBright2);
}

void randomServo(){
      int x1 = random(ServoPanLeftmax,ServoPanRightmax);
      int x2 = random(ServoPanLeftmax,ServoPanRightmax);
      int y1 = random(ServoTiltDownmax,ServoTiltUpmax);
      int y2 = random(ServoTiltDownmax,ServoTiltUpmax);
      writePan(Servo1_pan,x1);
      writePan(Servo2_pan,x2);
      writeTilt(Servo1_tilt,y1);
      writeTilt(Servo2_tilt,y2);
  
}

void checkDarkness(){
  if(lastBright1+lastBright2<16){
    if(!hasChecked){
      //darkTimer=0;
      darkTimer2=0;
      server_check();
      hasChecked=true;
    }else{
      darkTimer2++;
      int limit=10000;
      if(sequence==0)limit=15500;
      if(darkTimer2>limit){
        darkTimer2=0;
        hasChecked=false;
      }
    }
  }else{
    darkTimer++;
    hasChecked=false;
    if(darkTimer>15000){
      darkTimer=0;
      server_check();
    }
  }
}

void loop()
{

  
  //set_brightness(LightBrightness);
  //if(isConnected){
    if(sequence>=0){
      checkDarkness();
    }
  //}
    
  if(sequence==-2){
    digitalWrite(mosfet12,HIGH);
    rBlink(0.0043);
    sTimer++;
    if(sTimer>8000){
      sTimer=0;
      //sequence=1;
      MAX_BRIGHT=128;
      server_check();
    }
  }else if(sequence==-1){
    digitalWrite(mosfet12,HIGH);
    gBlink(0.0043);
    sTimer++;
    if(sTimer>8000){
      sTimer=0;
      sequence=1;
      server_check();
    }
  }else if(sequence==0){
    // reset servo position
//    Servo1_pan.write(90);
//    Servo1_tilt.write(120);  
//    Servo2_pan.write(90);
//    Servo2_tilt.write(120);
//    delay(250);
    digitalWrite(mosfet12,LOW);
    rgbled(0,0,0);
    
  }else if(sequence==4){
    digitalWrite(mosfet12,HIGH);
    //sequence=-1;
    movement0();
    sinus1+=0.0012;
    sinus2-=0.0023;
    bright1(200*(sin(sinus1)+1)/2);
    bright2(200*(sin(sinus2)+1)/2);
    rgbBlink(0.0042,0.0017);
  }else if(sequence==2){
    digitalWrite(mosfet12,HIGH);
    rgbBlink(0.00093,0.00077);
    movement1();
  }else if(sequence==1){
    digitalWrite(mosfet12,HIGH);
    if(pausi==0){
      lin1+=dlin1;
      if(lin1>1)dlin1=-0.0001;
      if(lin1<-0.05)dlin1=0.00010;
      lin2+=dlin2;
      if(lin2>1)dlin2=-0.0001;
      if(lin2<-0.05){
        dlin2=0.0001;
        pausi++;
      }
    }else{
        pausi++;
        if(pausi>1000){
          randomServo();
          pausi=0;
        }
    }
    
    float hlin1=lin1;
    float hlin2=lin2;
    if(hlin1<0){
      hlin1=0;
    }
    if(hlin2<0){
      hlin2=0;
    }
    lastBright1 = 255.0 * hlin1;
    lastBright2 = 255.0 * hlin2;
    bright1(lastBright1);
    
    int lastBright3 = 255-lastBright1;
    bright2(lastBright1);
    
    lastBright1=lastBright1/2;
    
    //rgbled(lastBright1,lastBright1,lastBright1);
    rgbled(0,0,0);
    //rgbBlink(0.0142,0.0057);
    
    
    
  }else if(sequence==3){
    digitalWrite(mosfet12,HIGH);
    lin1+=dlin1;
    if(lin1>1)dlin1=-0.0001;
    if(lin1<0)dlin1=0.0001;
    lin2+=dlin2;
    if(lin2>1)dlin2=-0.0001;
    if(lin2<0)dlin2=0.0001;
    
    lastBright1 = 255 - 255.0 * lin1;
    lastBright2 = 255 - 255.0 * lin2;
    bright1(lastBright1);
    
    int lastBright3 = 255-lastBright1;
    bright2(lastBright1);
    
    lastBright1=lastBright1/2;
    
    rgbBlink(0.0142,0.0057);
    
    //rgbled(lastBright1,lastBright1,lastBright1);
    movement0();
  }
  
  
  
  if (Serial.available() >0) {
    byte incoming = Serial.read();
    // turn off 12V power for shields
    if (incoming == 'q') {
      digitalWrite(mosfet12, LOW);
      Serial.println("mosfet off");
    }
    // turn on
    else if (incoming == 'o') {
      digitalWrite(mosfet12, HIGH);
    }
    
    else if(incoming == '0'){
      sequence=0;
    }else if(incoming == '1'){
      sequence=1;
    }else if(incoming == '2'){
      sequence=2;
    }else if(incoming == '3'){
      sequence=3;
    }else if(incoming == '4'){
      sequence=4;
    }

    //set speed
    else if (incoming == '5'){
      speed1-=0.00013;
      speed2-=0.00013;
    }
    else if (incoming == '6'){
      speed1+=0.00013;
      speed2+=0.00013;
    }else if(incoming == '7'){
      MAX_BRIGHT-=5;
      if(MAX_BRIGHT<MINMAX_BRIGHT)MAX_BRIGHT=MINMAX_BRIGHT;
    }else if(incoming == '8'){
      MAX_BRIGHT+=5;
      if(MAX_BRIGHT>MAXMAX_BRIGHT)MAX_BRIGHT=MAXMAX_BRIGHT;
    }
    // motor circles
    else if (incoming == 'm') {  
      for (int j=0;j<100;j+=20) {
         set_brightness(j);
         //draw_circle(Servo1_pan, Servo1_tilt, 50);
         //wdraw_circle(Servo2_pan, Servo2_tilt, 50);
      }
      
    }
    // motors right 1step
    else if (incoming == 's') {  
       moveServo(Servo2_pan,1);
       moveServo(Servo1_pan,1);
    }
    // motors left 1step
    else if (incoming == 'a') {  
       moveServo(Servo2_pan,-1);
       moveServo(Servo1_pan,-1);
    }   
    // motors up 1step
    else if (incoming == 'w') {  
       moveServo(Servo2_tilt,1);
       moveServo(Servo1_tilt,1);
    }
    // motors down 1step
    else if (incoming == 'z') {  
       moveServo(Servo2_tilt,-1);
       moveServo(Servo1_tilt,-1);
    }    
    // increase brightness
    else if (incoming == 'd') {
       LightBrightness +=1;
    }
    // decrease brightness
    else if (incoming == 'c') {
      LightBrightness -=1;
    }
    // increase brightness faster
    else if (incoming == 'f') {
      LightBrightness +=10;
    }
    // decrease brightness faster
    else if (incoming == 'v') {
      LightBrightness -=10;
    }
    // set full brightness
    else if (incoming == 'g') {
      set_brightness(100);
      LightBrightness = 100;
    }
    // check webclient
    else if (incoming == 'k') {
      server_check();
    }
    // test rgb aka double rainbow
    else if (incoming == 'u') {
       for (int i=0;i<255;i++) {
        analogWrite(RedPWM,255-i);
        analogWrite(BluePWM,255);
        analogWrite(GreenPWM,255);
        delay(5);
      }    
       for (int i=0;i<255;i++) {
        analogWrite(RedPWM,i);
        analogWrite(BluePWM,255);
        analogWrite(GreenPWM,255);
        delay(5);
      }     
      for (int i=0;i<255;i++) {
        analogWrite(GreenPWM,255-i);
        analogWrite(BluePWM,255);
        analogWrite(RedPWM,255);
        delay(5);
      }
      for (int i=0;i<255;i++) {
        analogWrite(GreenPWM,i);
        analogWrite(BluePWM,255);
        analogWrite(RedPWM,255);
        delay(5);
      }
      for (int i=0;i<255;i++) {
        analogWrite(BluePWM,255-i);
        analogWrite(RedPWM,255);
        analogWrite(GreenPWM,255);
        delay(5);
      }
       for (int i=0;i<255;i++) {
        analogWrite(BluePWM,i);
        analogWrite(RedPWM,255);
        analogWrite(GreenPWM,255);
        delay(5);
      }

    }
    else if (incoming == 'y') {
       
    }
    else if (incoming == 't') {
      int Servo1CurrentTemp = analogRead(Servo1Temp);
      Serial.print("Servo1 Temp: ");
      Serial.println(Servo1CurrentTemp);
      int Servo2CurrentTemp = analogRead(Servo2Temp);
      Serial.print("Servo2 Temp: ");
      Serial.println(Servo2CurrentTemp);
      int Servo3CurrentTemp = analogRead(Servo3Temp);
      Serial.print("Servo3 Temp: ");
      Serial.println(Servo3CurrentTemp);
      
    }
  }
}

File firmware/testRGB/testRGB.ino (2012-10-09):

#include <Servo.h> 
#include <SPI.h>
#include <WiFi.h>
#include <math.h>
/*
 * Color Wheel LED
 *
 * Loops a RGB LED attached to pins 9,10,11 through
 * all the "exterior" colors of a Color Wheel
 * 
 * The RGB LED uses a 3 component (red green blue) model which adds light colors to produce 
 * a composite color. But the RGB does not make easy to loop through a more
 * "natural" sequence of colors. The HSV (hue saturation value) model uses a color cylinder
 * in which each color is a point inside the cylinder. 
 * The hue is represented by the angle at which the point is, the saturation represents
 * the length (how close to the center the point is) and the value represent the height at
 * which the point is. 
 *
 * By cycling the hue value from 0 to 360 degrees, and keeping the saturation and value at 1
 * we can represent all the brightest colors of the wheel, in a nice natural sequence.
 *
 * The algorithm to convert a HSV value to a RGB value is taken from Chris Hulbert's blog (splinter)
 *
 * Created 1 January 2011
 * By Eduardo A. Flores Verduzco
 * http://eduardofv.com
 *
 * References:
 * http://en.wikipedia.org/wiki/HSL_and_HSV
 * http://en.wikipedia.org/wiki/Color_wheel
 * http://splinter.com.au/blog/?p=29
 *
 *
 */
const int mosfet12 =  30;  
void setup() {
  //Set the pins to analog output
  pinMode(5,OUTPUT);
  pinMode(2,OUTPUT);
  pinMode(3,OUTPUT);
  pinMode(mosfet12, OUTPUT);
    digitalWrite(mosfet12, HIGH);
}

void loop() {
  //The Hue value will vary from 0 to 360, which represents degrees in the color wheel
  for(int hue=0;hue<360;hue++)
  {
    setLedColorHSV(hue,1,1); //We are using Saturation and Value constant at 1
    delay(50); //each color will be shown for 10 milliseconds
  }
}

//Convert a given HSV (Hue Saturation Value) to RGB(Red Green Blue) and set the led to the color
//  h is hue value, integer between 0 and 360
//  s is saturation value, double between 0 and 1
//  v is value, double between 0 and 1
//http://splinter.com.au/blog/?p=29
void setLedColorHSV(int h, double s, double v) {
  //this is the algorithm to convert from RGB to HSV
  double r=0; 
  double g=0; 
  double b=0;

  double hf=h/60.0;

  int i=(int)floor(h/60.0);
  double f = h/60.0 - i;
  double pv = v * (1 - s);
  double qv = v * (1 - s*f);
  double tv = v * (1 - s * (1 - f));

  switch (i)
  {
  case 0: //rojo dominante
    r = v;
    g = tv;
    b = pv;
    break;
  case 1: //verde
    r = qv;
    g = v;
    b = pv;
    break;
  case 2: 
    r = pv;
    g = v;
    b = tv;
    break;
  case 3: //azul
    r = pv;
    g = qv;
    b = v;
    break;
  case 4:
    r = tv;
    g = pv;
    b = v;
    break;
  case 5: //rojo
    r = v;
    g = pv;
    b = qv;
    break;
  }

  //set each component to a integer value between 0 and 255
  int red=constrain((int)255*r,0,255);
  int green=constrain((int)255*g,0,255);
  int blue=constrain((int)255*b,0,255);

  setLedColor(red,green,blue);
}

//Sets the current color for the RGB LED
void setLedColor(int red, int green, int blue) {
  //Note that we are reducing 1/4 the intensity for the green and blue components because 
  //  the red one is too dim on my LED. You may want to adjust that.
  analogWrite(5,255-red); //Red pin attached to 9
  analogWrite(2,255-green/3); //Red pin attached to 9
  analogWrite(3,255-blue/3); //Red pin attached to 9
}

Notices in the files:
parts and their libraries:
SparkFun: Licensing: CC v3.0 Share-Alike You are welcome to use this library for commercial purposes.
